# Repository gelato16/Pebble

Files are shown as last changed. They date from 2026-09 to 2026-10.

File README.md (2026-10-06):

# Pebble the 65% keyboard
A 65% keyboard with fully custom parts designed using KiCAD and Solidworks. Made with a resin case, aluminum switch plate and hot swap Epomaker silent keyswitches. 
This project is my introduction to Solidworks as someone preparing for a new robotics season, When I started this project, I knew little about keyboards so I went with the essential 65% in order to keep things compact yet still having all the necessary keys, ensuring to include arrows for gaming. I named her pebble because of her smaller size, and cutesy frame design as well as the nature inspired look i origanlly had for her. 
Pebble originally had a side bar intended for stickers but with more adjustments I decided on a more compact under the spacebar component set up in order to make many of my calculations easier and lower risk of mistakes. 
features:
- 65% QWERTY layout
- Sandwich style assembly
- 6.25U spacebar
- Plate-mounted switches
- Custom PCB
- USB-C connection
- Custom switch plate

CAD photos (CAD has since been updated to accomidate standard 6.25u spacebar):




PCB photos:





assembly guild: 
1. Solder all parts onto PCB (including capacitors, diodes and hot swap sockets)
2. Flash the microcontroller (Code is in "Code" folder)
3. lower the pcb into the casing
4. attack stablizers to the underside of the switch plate
5. place switch plate on top of casing (be careful to align the keys)
6. press all 69 keys into their positions
7. place bezel on top of switch plate and screw into place (9 M3 16mm screws)
8. click keycaps onto key switches

Pictures of assembly design process below: 


Bill of materials:
https://docs.google.com/spreadsheets/d/1lCmeEfUbG34g1hUgpbVch2w63U2JIJnhS8jueZ3TIsw/edit?usp=sharing 
| Id | Designator | Footprint | Quantity | Designation | Subtotal | Link |
| :--- | :--- | :--- | :--- | :--- | :--- | :--- |
| 1 | MX1-MX69 | SW_MX_HS_CPG151101S11_1u | 69(4 packs) | MX_SW_HS | $33.96 | https://www.amazon.ca/TOGEVAL-Hot-swappable-Mechanical-Keyboard-Assembly/dp/B0GHMCD6SP |
| 2 | U1 | LQFP-48_7x7mm_P0.5mm | 1 | STM32F072CBT6 | $10.47 | https://www.digikey.ca/en/products/detail/stmicroelectronics/STM32F072CBT6/4815292 |
| 3 | C1, C3, C4, C5, C6 | C_1206_3126Metric | 7+1 | 100nF | $4.16 | https://www.digikey.com/en/products/detail/kemet/C1206C104KARACTU/992167 |
| 4 | C9, C10 | C_1206_3126Metric | 2 | 1uF | $1.26 | https://www.digikey.ca/en/products/detail/yageo/CC1206KKX7R7BB105/302915 |
| 5 | R1 - R4 | R_1206_3126Metric | 4 | 5.1k | $0.40 | https://www.digikey.com/en/products/detail/stackpole-electronics-inc/RMCF1206FT5K10/1759499 |
| 6 | BOOT1, RST1 | SW_SPST_TL3342 | 2 | SW_SPST | $2.26 | https://jlcpcb.com/partdetail/ESwitch-TL3342F260QG/C2886894 |
| 7 | J1 | USB_C_Receptacle_HRO_TYPE-C-31-M-12 | 1 | USB_C_Receptacle_USB2.0 | $3.84 | https://www.digikey.ca/en/products/detail/same-sky-formerly-cui-devices/UJ31-CH-G2-SMT-TR/8024063 |
| 8 | F1 | Fuse_1206_3216Metric | 1 | 500mA | $0.46 | https://www.lcsc.com/product-detail/C135341.html |
| 9 | U5 | C_0402_1005Metric | 1 | TXB0101 | $0.71 | https://www.lcsc.com/product-detail/C324081.html |
| 10 | U3 | SOT-23 | 1 | XC6206PxxxMR-Regulator_Linear | $0.72 | https://www.lcsc.com/product-detail/C5446.html |
| 11 | D1-D69 | D_SOD-123 | 69+5 | D_small | $5.42 | https://www.digikey.ca/en/products/detail/shenzhen-slkormicro-semicon-co-ltd/1N4148W/21853071 |
| 12 | U2 | SOT-143 | 1 | PRTR5V0U2X | $0.43 | https://www.lcsc.com/product-detail/C12333.html |
| 13 | C2 | C_1206_3216Metric | 1 | 10uF | $1.49 | https://www.digikey.ca/en/products/detail/kemet/C1206C106K8RACTU/1090842 |
| 14 | C43, C44 | C_1206_3216Metric | 2 | 0.1uF | $0.80 | https://www.digikey.ca/en/products/detail/tdk/C3216X7R2A104M160AA/513969 |
| 15 | J2 | PinHeader_1x05_P2.54mm_Vertical | 1 | Conn_01x05 | $0.29 | https://www.digikey.ca/en/products/detail/harwin-inc/M20-9990546/3728232 |
| 16 | J3 | PinHeader_1x06_P2.54mm_Vertical | 1 | Conn_01x06 | $1.39 | https://www.digikey.ca/en/products/detail/sullins-connector-solutions/PEC06SAFN/859339 |
| | | | | | | |
| Physical (already purchased): | | | | | | |
| Id | Name | quantity | subtotal | link | | |
| 1 | EPOMAKER Lilac Silent Tactile Switch Set | 1 | $38 | https://epomaker.ca/products/epomaker-lilac-silent-tactile-switch-set?_pos=1&_psq=lilac&_psid=7e47da251&_ss=e | | |
| 2 | DUROCK Plate Mount Stabilizer V3 | 1 | $19.93 | https://www.amazon.ca/dp/B0CTHT34MJ?ref=ppx_yo2ov_dt_b_fed_asin_title&th=1 | | |
| 3 | dagaladoo Coffee Cat 140key keycaps,XDA Profile,dye Sublimation PBT Custom keycap with Key Puller for Gateron MX Switch | 1 | $30 | https://www.amazon.ca/dp/B0CF1ZS6D4?ref=ppx_yo2ov_dt_b_fed_asin_title&th=1 | | |
| | | | | | | |
| Materials: | | | | | | |
| ID | Name | Quantity | subtotal | Link | | |
| 1 | Soldering Iron | 1 | $26 | https://www.amazon.ca/gp/product/B07RY6P4XH/ref=ox_sc_act_title_3?smid=A3W1GP4TQNGUVI&psc=1 | | |
| 2 | Solder | 1 | $7.50 | | | |
| 3 | flux + wick | 1 | $15 | | | |
| | | | | | | |
| JLC estimates: $90 | | | | | | |
| | | | | | | |
| Total: 294.16 | | | | | | |
| | | | | | | |
| funds completed: | Funds required: | | | | | |
| $100 | 194.16 | | | | | |
| | | | | | | |

All designs complete, assembly ongoing
(designed using Kicad, Solidworks and sketchbook)
(files with numbers ex:open2, are completed(not verified works.)

Known issues: None, 
Credits: My father for introducing me to all this. 
Sanity checked by my lovely best friend

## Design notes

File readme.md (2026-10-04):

# pebble

pebble

*A short description of the keyboard/project*

* Keyboard Maintainer: [Justine](https://github.com/gelato16)
* Hardware Supported: *The PCBs, controllers supported*
* Hardware Availability: *Links to where you can find this hardware*

Make example for this keyboard (after setting up your build environment):

    make pebble:default

Flashing example for this keyboard:

    make pebble:default:flash

See the [build environment setup](https://docs.qmk.fm/#/getting_started_build_tools) and the [make instructions](https://docs.qmk.fm/#/getting_started_make_guide) for more information. Brand new to QMK? Start with our [Complete Newbs Guide](https://docs.qmk.fm/#/newbs).

## Bootloader

Enter the bootloader in 3 ways:

* **Bootmagic reset**: Hold down the key at (0,0) in the matrix (usually the top left key or Escape) and plug in the keyboard
* **Physical reset button**: Briefly press the button on the back of the PCB - some may have pads you must short instead
* **Keycode in layout**: Press the key mapped to `QK_BOOT` if it is available

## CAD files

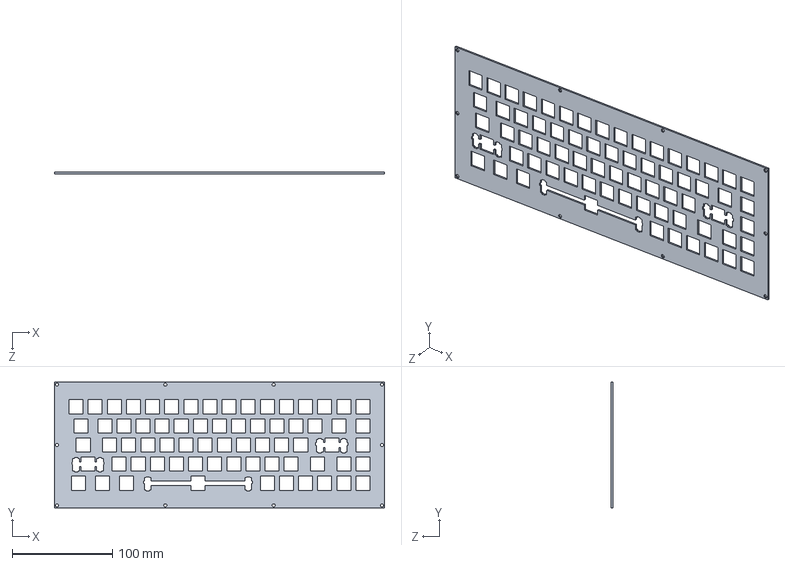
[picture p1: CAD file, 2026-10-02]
Case/Switchplatefinal.STEP
328.8 x 125.3 x 1.50 mm

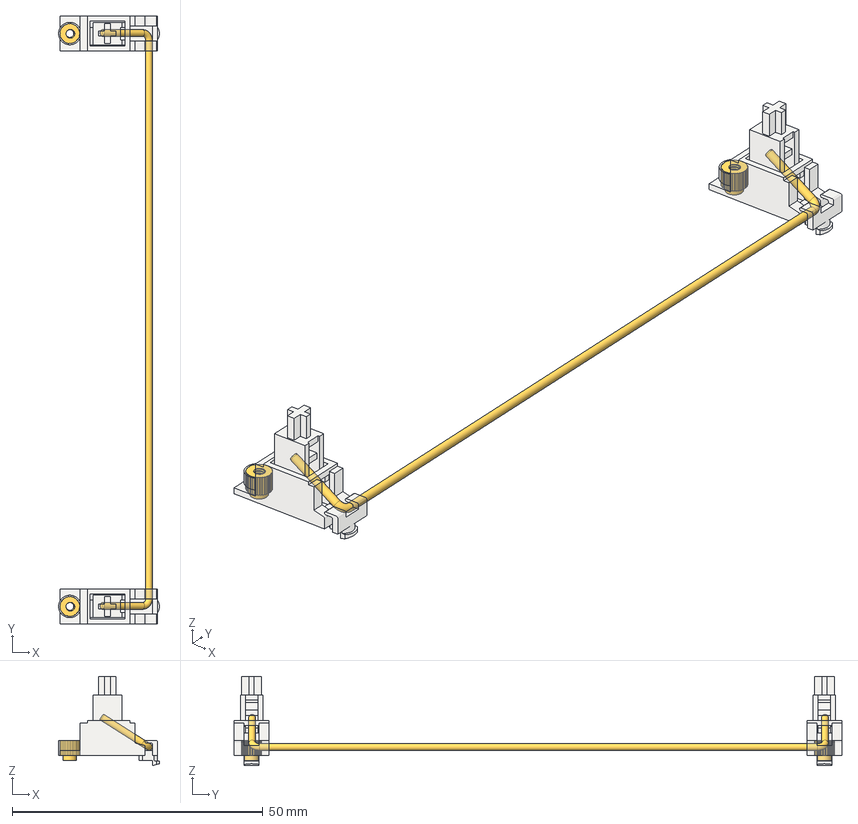
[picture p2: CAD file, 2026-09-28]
Case/7U Stabilizer.step
20.1 x 121.3 x 17.8 mm
Stabilizer Housing x 2
M2 Insert x 2
Stabilizer Insert x 2
7U Stabilizer Bar

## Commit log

2026-09-28 Rename keyboard pcb again.step to keyboard pcb.step
    [keyboard pcb again.step, keyboard pcb.step]
2026-09-28 Rename keyboard pcb.step to PCB/keyboard pcb.step
    [keyboard pcb.step]
2026-09-28 Rename keyboard pcb again.step to PCB/keyboard pcb CAD.step
    [keyboard pcb CAD.step, keyboard pcb again.step]
2026-09-28 Update and rename keyboard pcb.step to keyboard pcb(faulty).step
    [keyboard pcb(faulty).step]
2026-09-28 Add files via upload
    used for assembly (not by me)
    [Cherry MX.STEP]
2026-09-28 Rename Cherry MX.STEP to Case/Cherry MX.STEP
    [Cherry MX.STEP]
2026-09-28 Add files via upload
    used in assembly(not made by me)
    [7U Stabilizer.step]
2026-09-28 Rename 7U Stabilizer.step to Case/7U Stabilizer.step
    [7U Stabilizer.step]
2026-09-28 Rename keyboard pcb cad.step to PCB/keyboard pcb cad.step
    [keyboard pcb cad.step]
